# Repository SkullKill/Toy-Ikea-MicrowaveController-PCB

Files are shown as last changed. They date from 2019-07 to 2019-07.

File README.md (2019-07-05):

# Toy-Ikea-MicrowaveController-PCB
PCB for Microwave Controller for Ikea Kitchen DUKTIG

FYI Gerber files are in the release section

https://github.com/SkullKill/Toy-Ikea-MicrowaveController-PCB/releases

  Toy-Ikea-MicrowaveController
  
  Toy Ikea Microwave Controller

  Microware Controller (Arduino Based)
  
  for Ikea Kitchen DUKTIG
  
  LEDBERG LED spotlight
  
  SKaccess by Simon Kong

  www.skaccess.com
  
  ATTiny841









  ------------------------------------------------------------
  ## Features
  
  increment timer by 5 sec from 0 to 60 sec
  
  increment timer by 10 sec from 1min to 5 min
  
  increment timer by 30 sec from 5min onwards to 51min
  
  press the rotary knob to start/pause countdown
  
  light will be on when countdown is active
  
  low tone buzzer noise when counting down to simulate the microwave being on
  
  opening the door while countdown is on will pause countdown
  
  when the door is open, light will be on
  
  when the countdown finishes, will display "End", if the door is not open,
  
    it will do the End melody again every 2 min, untill the door is open.
    
    this is to remind the user that there is still food in the microwave.

  V 1.0 - 30/06/2019 - Initial Release
  ------------------------------------------------------------
  ## PCB Board Used
  
  https://www.skstore.com.au/electronics/pcb/Toy-Ikea-MicrowaveController

  https://github.com/SkullKill/Toy-Ikea-MicrowaveController-PCB

  more pictures in the wiki
  
  https://github.com/SkullKill/Toy-Ikea-MicrowaveController-PCB/wiki
  
  ------------------------------------------------------------
  ## Code Used
  
  https://github.com/SkullKill/Toy-Ikea-MicrowaveController
  
  ------------------------------------------------------------
  ## Video
  
  https://youtu.be/BQZ9P_Z0Fzc

  ------------------------------------------------------------
  ## Product Used (included)
  
  15mm Aluminium Knob
  
  10mm Spacer/Standoff and M3 Screws
  
  ------------------------------------------------------------
  ## Product Used (not included)
  
  - Ikea DUKTIG Play kitchen, birch
  
  Article Number : 403.199.73
  
  https://www.ikea.com/au/en/catalog/products/40319973/

  - Ikea LEDBERG LED spotlight, white, 4 pack
  
  Article Number : 103.517.33
  
  https://www.ikea.com/au/en/catalog/products/10351733/
  
  Note: the cable with the Dark Lines is the -ve/gnd cable. 
  
  But better to double check with a multimeter.

  - magnetic door sensor (reed switch) [could also use a micro switch]
  
  - 3mm Acrylic sheet

  - 50mm L Angle Bracket
  
  https://www.bunnings.com.au/zenith-50mm-zinc-plated-angle-brackets-4-pack_p2760232

  - various screws and bolts 
  
  - 4G X 12mm timber screws
  
  - washer 5/32" / M4
  
  - Bolts & Nuts 3/16" X 15mm / M5

  ------------------------------------------------------------
  Library Used
  
  https://github.com/SpenceKonde/ATTinyCore
  
  https://miguelpynto.github.io/ShiftDisplay/
  
  https://www.pjrc.com/teensy/td_libs_Encoder.html

  ------------------------------------------------------------
  Sketch uses 6850 bytes (90%) of program storage space. Maximum is 7552 bytes.
  Global variables use 226 bytes (44%) of dynamic memory, leaving 286 bytes for local variables. Maximum is 512 bytes.

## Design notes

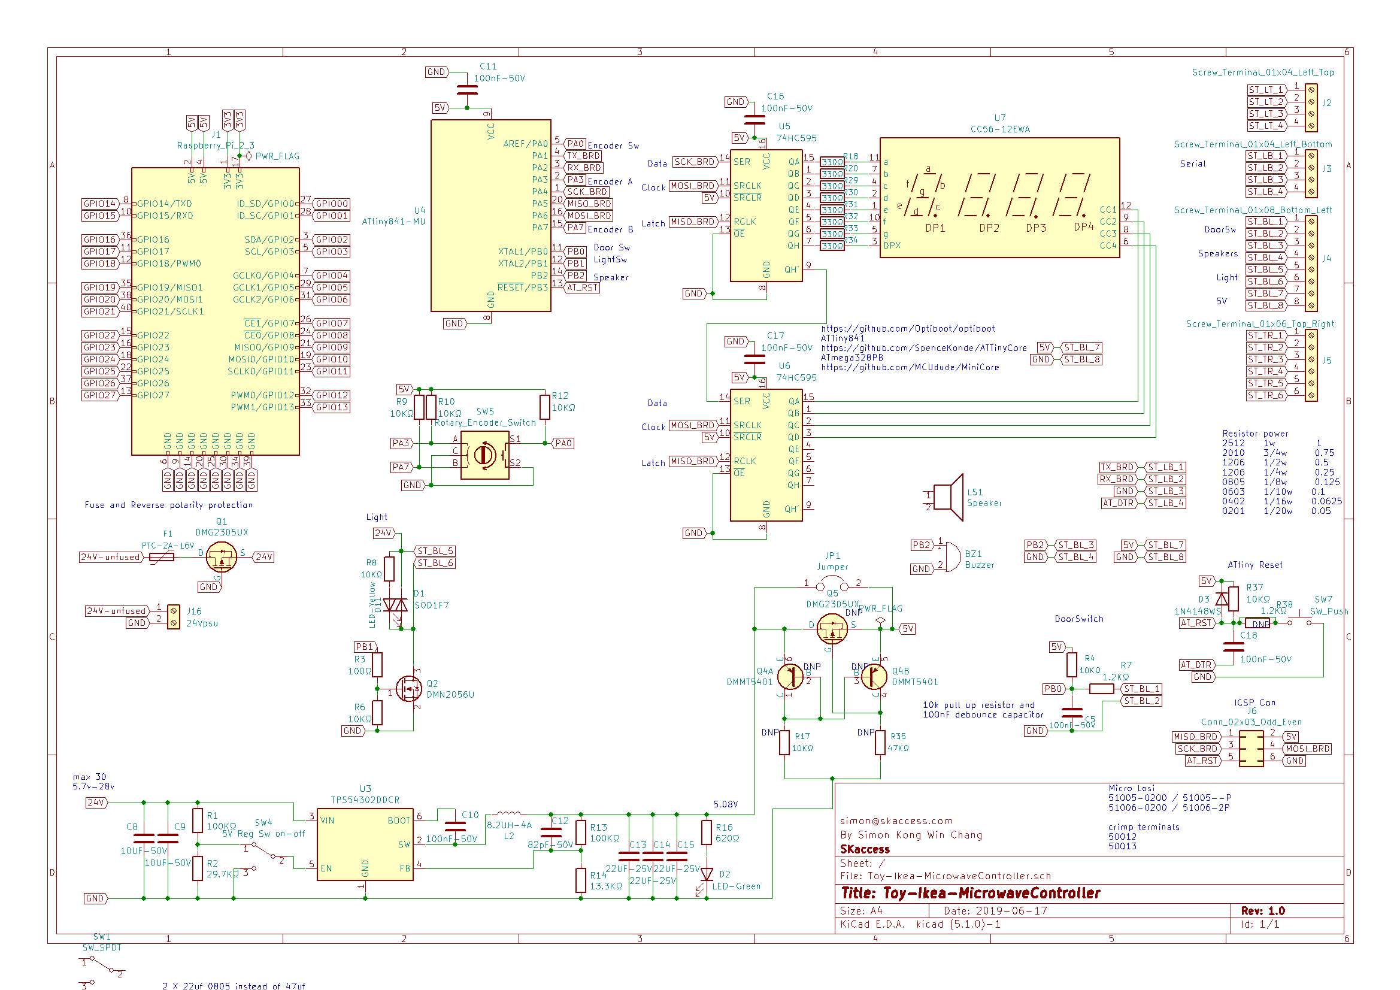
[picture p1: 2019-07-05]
Toy-Ikea-MicrowaveController-schematics-V1.0.jpg

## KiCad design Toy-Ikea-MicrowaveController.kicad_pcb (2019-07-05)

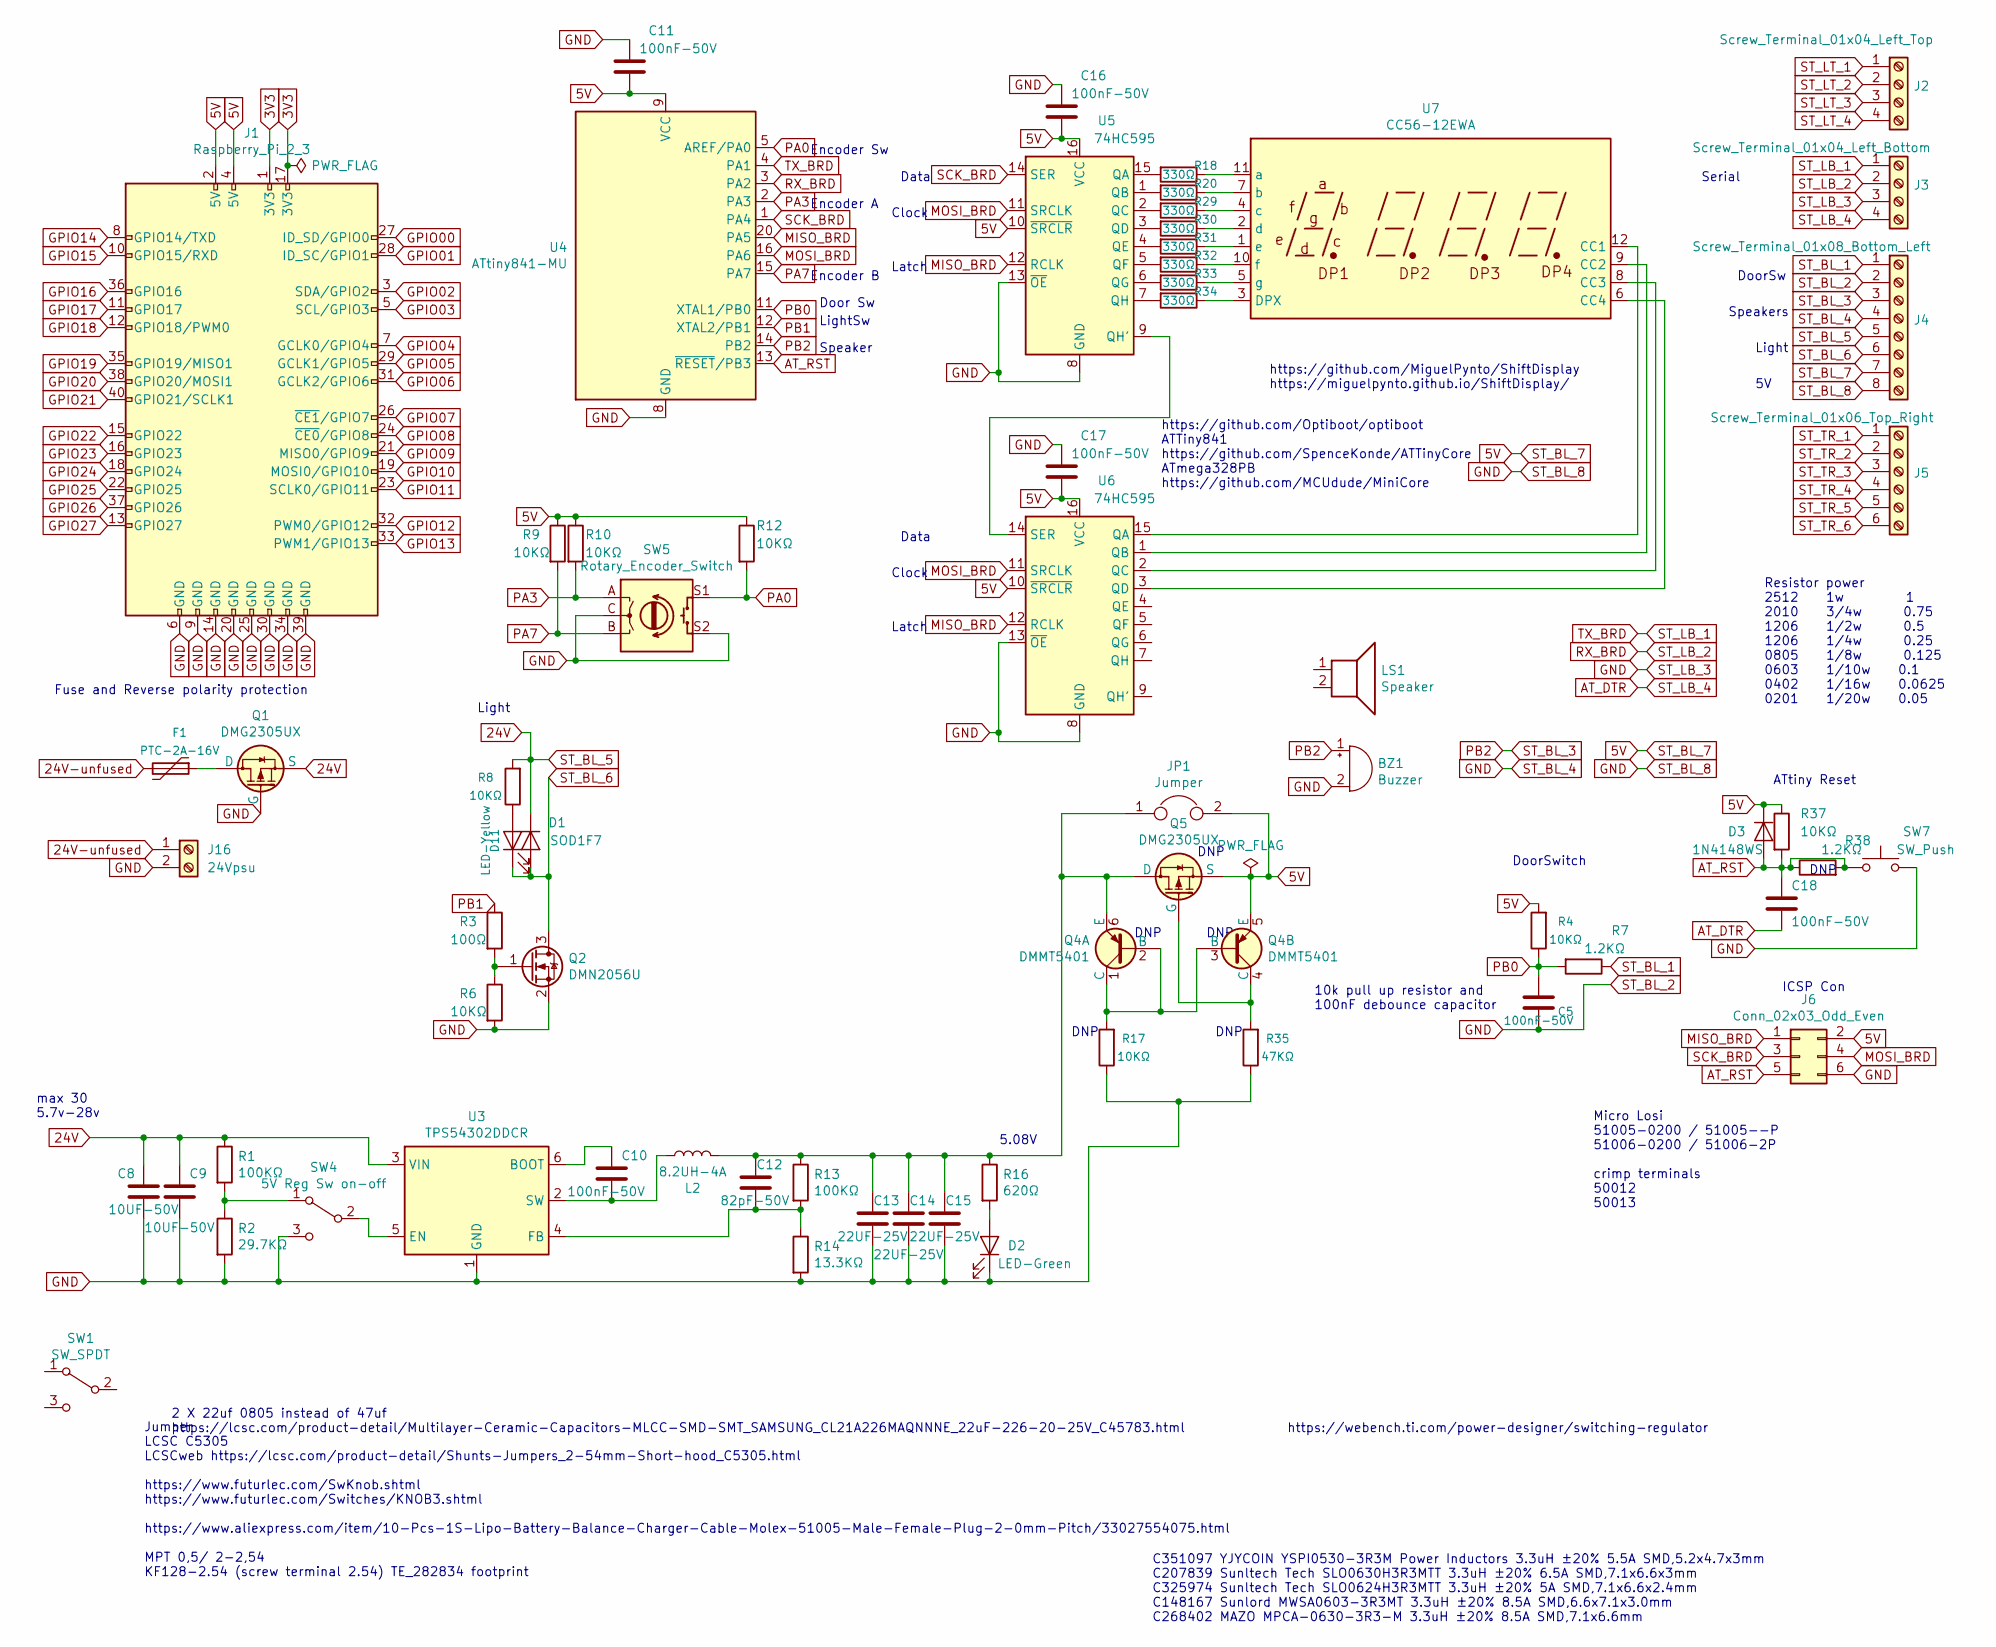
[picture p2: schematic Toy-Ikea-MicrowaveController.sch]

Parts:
BZ1: Buzzer; Buzzer_12x9.5RM5.0; MPN ZL-YDW1207-4005PA-5.0; LCSC C219727
C5, C10, C11, C16, C17, C18: 100nF-50V; C_0603_1608Metric; MPN AC0603KRX7R9BB104; LCSC C149620
C8, C9: 10UF-50V; C_1206_3216Metric; MPN CL31A106KBHNNNE; LCSC C13585
C12: 82pF-50V; C_0402_1005Metric; MPN CL05C820JB5NNNC; LCSC C13532
C13, C14, C15: 22UF-25V; C_0805_2012Metric; MPN CL21A226MAQNNNE; LCSC C45783
D1: SOD1F7; D_SOD-123; MPN SOD1F7; LCSC C33221
D2: LED-Green; LED_0603_1608Metric; MPN ORH-G36G; LCSC C205443
D3: 1N4148WS; D_SOD-323; MPN 1N4148WS; LCSC C2128
D11: LED-Yellow; LED_0603_1608Metric; MPN FC-DA1608HYK-588J; LCSC C84268
F1: PTC-2A-16V; Fuse_1812_4532Metric_Pad1.30x3.40mm_HandSolder; MPN SCF200-16-1812R; LCSC C305617
J1: Raspberry_Pi_2_3; PinSocket_2x20_P2.54mm_Vertical; LCSC C50982
J2: Screw_Terminal_01x04_Left_Top; TerminalBlock_TE_282834-4_1x04_P2.54mm_Horizontal; MPN KF128-2.54-4P
J3: Screw_Terminal_01x04_Left_Bottom; TerminalBlock_TE_282834-4_1x04_P2.54mm_Horizontal; MPN KF128-2.54-4P
J4: Screw_Terminal_01x08_Bottom_Left; TerminalBlock_TE_282834-8_1x08_P2.54mm_Horizontal; MPN KF128-2.54-8P
J5: Screw_Terminal_01x06_Top_Right; TerminalBlock_TE_282834-6_1x06_P2.54mm_Horizontal; MPN KF128-2.54-6P
J6: Conn_02x03_Odd_Even; PinHeader_2x03_P2.54mm_Vertical; LCSC C65114
J16: 24Vpsu; TerminalBlock_bornier-2_P5.08mm; MPN WJ126V-5.0-2P; LCSC C8404
JP1: Jumper; PinHeader_1x02_P2.54mm_Vertical; LCSC C124375
L2: 8.2UH-4A; L_6.3x6.3_H3_HandSolder; MPN BCIHP0735-8R2M; LCSC C237933
LS1: Speaker; TerminalBlock_TE_282834-2_1x02_P2.54mm_Horizontal; LCSC C391012
Q1, Q5: DMG2305UX; SOT-23; MPN DMG2305UX-13; LCSC C144153
Q2: DMN2056U; SOT-23; MPN DMN2056U-7; LCSC C332302
Q4: DMMT5401; SOT-23-6; MPN DMMT5401-7-F; LCSC C154733
R1: 100KΩ; R_0603_1608Metric; MPN RC0603FR-07100KL; LCSC C14675
R2: 29.7KΩ; R_0603_1608Metric; MPN RC0603FR-0729K4L; LCSC C137752
R3: 100Ω; R_0603_1608Metric; MPN RC0603FR-07100RL; LCSC C105588
R4, R6, R8, R9, R10, R12, R17, R37: 10KΩ; R_0603_1608Metric; MPN RC0603FR-0710KL; LCSC C98220
R7, R38: 1.2KΩ; R_0603_1608Metric; MPN RC0603FR-071K2L; LCSC C114605
R13: 100KΩ; R_0603_1608Metric; MPN RTT031003FTP; LCSC C103200
R14: 13.3KΩ; R_0603_1608Metric; MPN RC0603FR-0713K3L; LCSC C185373
R16: 620Ω; R_0603_1608Metric; MPN RTT036200FTP; LCSC C103749
R18, R20, R29, R30, R31, R32, R33, R34: 330Ω; R_0603_1608Metric; MPN RC0603FR-07330RL; LCSC C105881
R35: 47KΩ; R_0603_1608Metric; MPN AC0603FR-0747KL; LCSC C111134
SW1: SW_SPDT; SW_CuK_OS102011MA1QN1_SPDT_Angled; MPN SK-12D02-VG5; LCSC C136722
SW4: 5V Reg Sw on-off; SW_SPDT_PCM12; MPN K3-1296S-E2; LCSC C136659
SW5: Rotary_Encoder_Switch; RotaryEncoder_Alps_EC11E-Switch_Vertical_H20mm; MPN EC11E1834403; LCSC C361165
SW7: SW_Push; SW_SPST_TL3305A; LCSC C174049
U3: TPS54302DDCR; SOT-23-6; MPN TPS54302DDCR; LCSC C311983
U4: ATtiny841-MU; QFN-20-1EP_4x4mm_P0.5mm_EP2.6x2.6mm; MPN ATTINY841-MU
U5, U6: 74HC595; SOIC-16_3.9x9.9mm_P1.27mm; MPN 74HC595D,118; LCSC C5947
U7: CC56-12EWA; CA56-12EWA; LCSC C10709

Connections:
3V3: J1.1 (3V3), J1.17 (3V3)
5V: C11.2, C16.2, C17.2, D3.1 (K), J1.2 (5V), J1.4 (5V), J4.7, J6.2, JP1.2, Q4.5 (E), Q5.2 (S), R4.2, R9.1, R10.1, R12.1, R37.1, U4.9 (VCC), U5.10 (~SRCLR), U5.16 (VCC), U6.10 (~SRCLR), U6.16 (VCC)
24V: C8.1, C9.1, D1.1 (K), J4.5, Q1.2 (S), R1.1, R8.2, U3.3 (VIN)
24V-unfused: F1.2, J16.1
AT_DTR: C18.2, J3.4
AT_RST: C18.1, D3.2 (A), J6.5, R37.2, R38.1, R38.2, SW7.1, U4.13 (~RESET~/PB3)
GND: BZ1.2 (+), C5.2, C8.2, C9.2, C11.1, C13.2, C14.2, C15.2, C16.1, C17.1, D2.1 (K), J1.6 (GND), J1.9 (GND), J1.14 (GND), J1.20 (GND), J1.25 (GND), J1.30 (GND), J1.34 (GND), J1.39 (GND), J3.3, J4.2, J4.4, J4.8, J6.6, J16.2, Q1.1 (G), Q2.2 (S), R2.2, R6.2, R14.2, R17.1, R35.1, SW4.3 (C), SW5.C, SW5.S2, SW7.2, U3.1 (GND), U4.8 (GND), U4.21 (GND), U5.8 (GND), U5.13 (~OE), U6.8 (GND), U6.13 (~OE)
GPIO00: J1.27 (ID_SD/GPIO0)
GPIO01: J1.28 (ID_SC/GPIO1)
GPIO02: J1.3 (SDA/GPIO2)
GPIO03: J1.5 (SCL/GPIO3)
GPIO04: J1.7 (GCLK0/GPIO4)
GPIO05: J1.29 (GCLK1/GPIO5)
GPIO06: J1.31 (GCLK2/GPIO6)
GPIO07: J1.26 (~CE1~/GPIO7)
GPIO08: J1.24 (~CE0~/GPIO8)
GPIO09: J1.21 (MISO0/GPIO9)
GPIO10: J1.19 (MOSI0/GPIO10)
GPIO11: J1.23 (SCLK0/GPIO11)
GPIO12: J1.32 (PWM0/GPIO12)
GPIO13: J1.33 (PWM1/GPIO13)
GPIO14: J1.8 (GPIO14/TXD)
GPIO15: J1.10 (GPIO15/RXD)
GPIO16: J1.36 (GPIO16)
GPIO17: J1.11 (GPIO17)
GPIO18: J1.12 (GPIO18/PWM0)
GPIO19: J1.35 (GPIO19/MISO1)
GPIO20: J1.38 (GPIO20/MOSI1)
GPIO21: J1.40 (GPIO21/SCLK1)
GPIO22: J1.15 (GPIO22)
GPIO23: J1.16 (GPIO23)
GPIO24: J1.18 (GPIO24)
GPIO25: J1.22 (GPIO25)
GPIO26: J1.37 (GPIO26)
GPIO27: J1.13 (GPIO27)
MISO_BRD: J6.1, U4.20 (PA5), U5.12 (RCLK), U6.12 (RCLK)
MOSI_BRD: J6.4, U4.16 (PA6), U5.11 (SRCLK), U6.11 (SRCLK)
unnamed: C10.1, U3.6 (BOOT)
unnamed: C10.2, L2.1, U3.2 (SW)
unnamed: C12.1, C13.1, C14.1, C15.1, JP1.1, L2.2, Q4.6 (E), Q5.3 (D), R13.1, R16.1
unnamed: C12.2, R13.2, R14.1, U3.4 (FB)
unnamed: D2.2 (A), R16.2
unnamed: D11.2 (A), R8.1
unnamed: F1.1, Q1.3 (D)
unnamed: Q2.1 (G), R3.2, R6.1
unnamed: Q4.1 (C), Q4.2 (B), Q4.3 (B), R17.2
unnamed: Q4.4 (C), Q5.1 (G), R35.2
unnamed: R1.2, R2.1, SW4.1 (A)
unnamed: R18.1, U7.11 (a)
unnamed: R18.2, U5.15 (QA)
unnamed: R20.1, U7.7 (b)
unnamed: R20.2, U5.1 (QB)
unnamed: R29.1, U7.4 (c)
unnamed: R29.2, U5.2 (QC)
unnamed: R30.1, U7.2 (d)
unnamed: R30.2, U5.3 (QD)
unnamed: R31.1, U7.1 (e)
unnamed: R31.2, U5.4 (QE)
unnamed: R32.1, U7.10 (f)
unnamed: R32.2, U5.5 (QF)
unnamed: R33.1, U7.5 (g)
unnamed: R33.2, U5.6 (QG)
unnamed: R34.1, U7.3 (DPX)
unnamed: R34.2, U5.7 (QH)
unnamed: SW4.2 (B), U3.5 (EN)
unnamed: U5.9 (QH'), U6.14 (SER)
unnamed: U6.1 (QB), U7.9 (CC2)
unnamed: U6.2 (QC), U7.8 (CC3)
unnamed: U6.3 (QD), U7.6 (CC4)
unnamed: U6.15 (QA), U7.12 (CC1)
PA0: R12.2, SW5.S1, U4.5 (AREF/PA0)
PA3: R10.2, SW5.A, U4.2 (PA3)
PA7: R9.2, SW5.B, U4.15 (PA7)
PB0: C5.1, R4.1, R7.2, U4.11 (XTAL1/PB0)
PB1: R3.1, U4.12 (XTAL2/PB1)
PB2: BZ1.1 (-), J4.3, U4.14 (PB2)
RX_BRD: J3.2, U4.3 (PA2)
SCK_BRD: J6.3, U4.1 (PA4), U5.14 (SER)
ST_BL_1: J4.1, R7.1
ST_BL_6: D1.2 (A), D11.1 (K), J4.6, Q2.3 (D)
ST_LB_1: J3.1, U4.4 (PA1)
ST_TR_1: J5.1
ST_TR_2: J5.2
ST_TR_3: J5.3
ST_TR_4: J5.4
ST_TR_5: J5.5
ST_TR_6: J5.6

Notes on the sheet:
https://webench.ti.com/power-designer/switching-regulator
10k pull up resistor and 100nF debounce capacitor
Jumper LCSC C5305 LCSCweb https://lcsc.com/product-detail/Shunts-Jumpers_2-54mm-Short-hood_C5305.html https://www.futurlec.com/SwKnob.shtml https://www.futurlec.com/Switches/KNOB3.shtml https://www.aliexpress.com/item/10-Pcs-1S-Lipo-Battery-Balance-Charger-Cable-Molex-51005-Male-Female-Plug-2-0mm-P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
2 X 22uf 0805 instead of 47uf https://lcsc.com/product-detail/Multilayer-Ceramic-Capacitors-MLCC-SMD-SMT_SAMSUNG_CL21A226MAQNNNE_22uF-226-20-25V_C45783.html
C351097 YJYCOIN YSPI0530-3R3M Power Inductors 3.3uH ±20% 5.5A SMD,5.2x4.7x3mm C207839 Sunltech Tech SLO0630H3R3MTT 3.3uH ±20% 6.5A SMD,7.1x6.6x3mm C325974 Sunltech Tech SLO0624H3R3MTT 3.3uH ±20% 5A SMD,7.1x6.6x2.4mm C148167 Sunlord MWSA0603-3R3MT 3.3uH ±20% 8.5A SMD,6.6x7.1x3.0mm C268402 MAZO MPCA-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
Fuse and Reverse polarity protection
Resistor power 2512 1w 1 2010 3/4w 0.75 1206 1/2w 0.5 1206 1/4w 0.25 0805 1/8w 0.125 0603 1/10w 0.1 0402 1/16w 0.0625 0201 1/20w 0.05
Micro Losi 51005-0200 / 51005--P 51006-0200 / 51006-2P crimp terminals 50012 50013
5.08V
ATtiny Reset
ICSP Con
Clock
Latch
Data
https://github.com/MiguelPynto/ShiftDisplay https://miguelpynto.github.io/ShiftDisplay/
Light
Speakers
DoorSw
Serial
Encoder A
Encoder B
Encoder Sw
Speaker
Door Sw
LightSw
DoorSwitch
https://github.com/Optiboot/optiboot ATTiny841 https://github.com/SpenceKonde/ATTinyCore ATmega328PB https://github.com/MCUdude/MiniCore
max 30 5.7v-28v
DNP

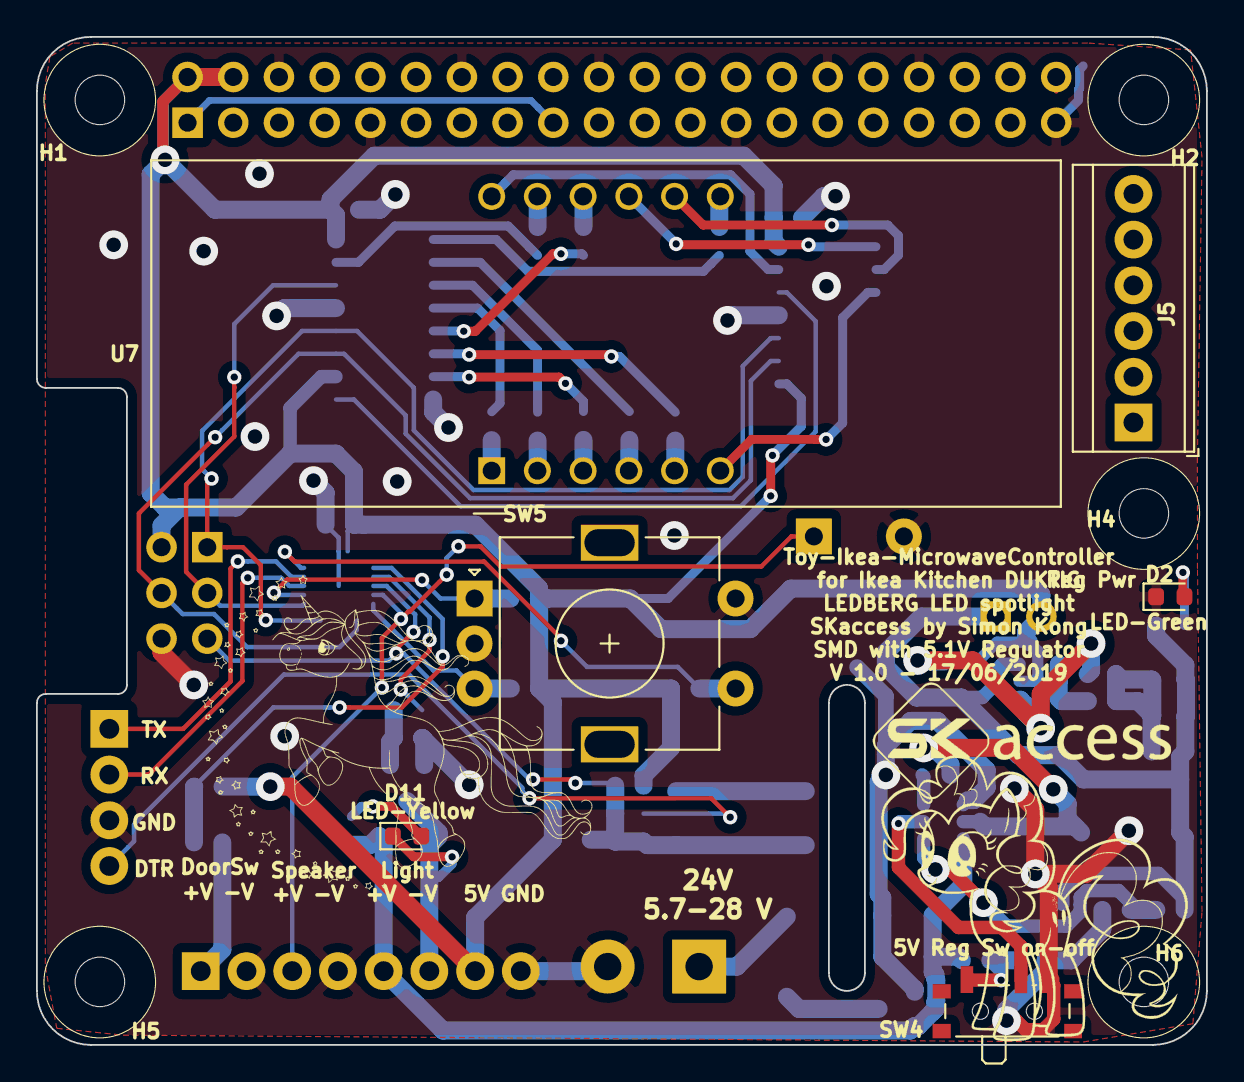
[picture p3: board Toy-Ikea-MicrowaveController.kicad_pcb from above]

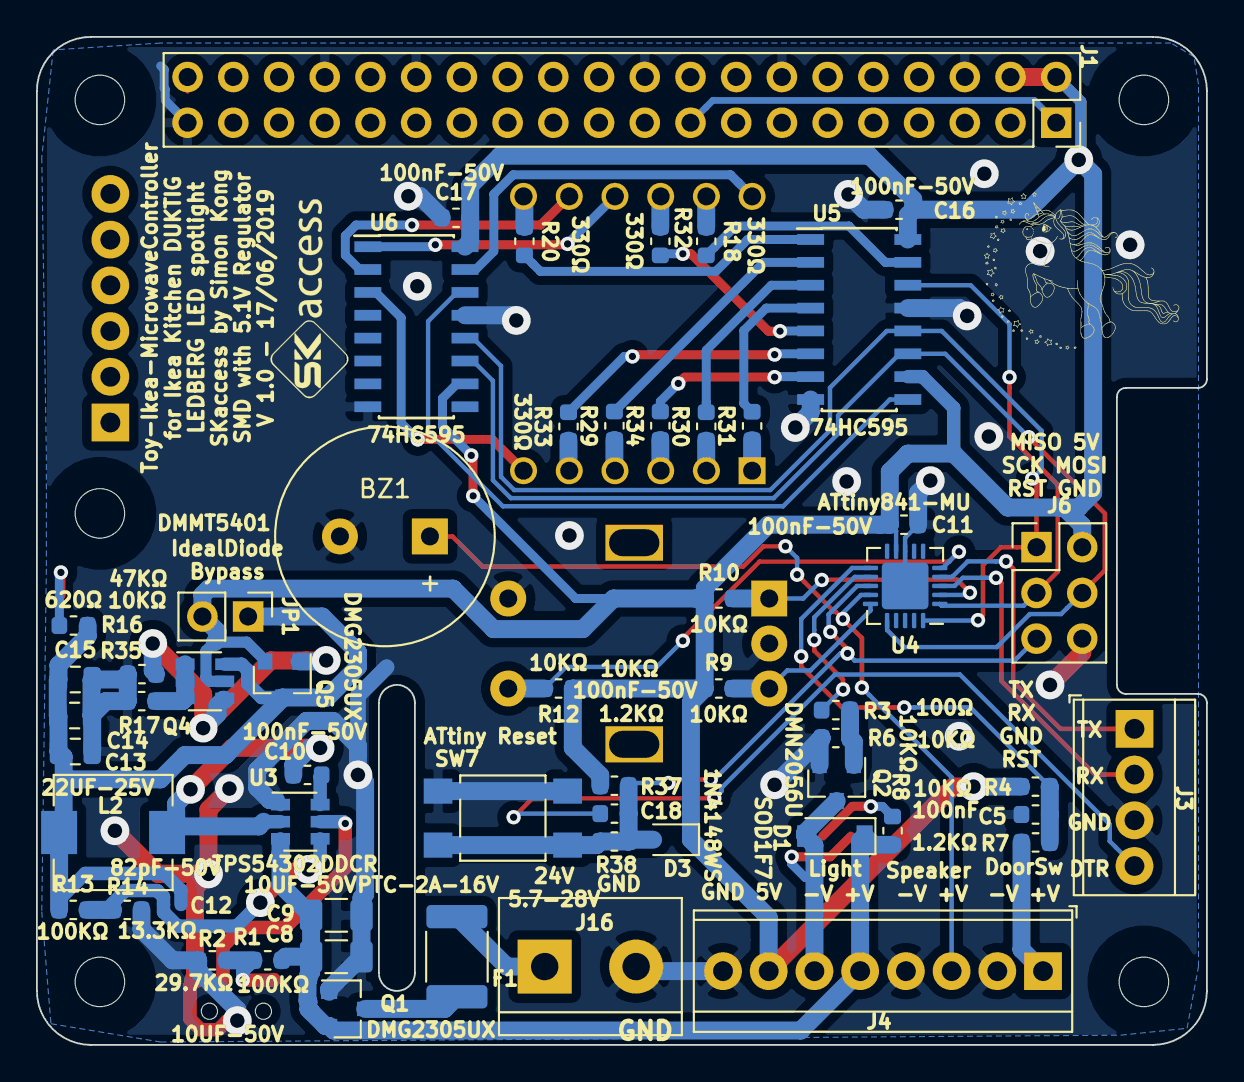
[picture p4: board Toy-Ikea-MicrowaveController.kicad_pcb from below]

Board: 2 copper layers, 65.0 x 56.0 mm, 68 parts (57 on the bottom side), 53 nets.

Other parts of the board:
H1, H2, H4, H5, H6: MountingHole; MountingHole_2.75mm_M2.5_NoPad
